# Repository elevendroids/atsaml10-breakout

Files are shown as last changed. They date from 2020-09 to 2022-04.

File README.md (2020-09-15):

# ATSAML1x Breakout Board (Rev. A)

Small breakout board designed for the [ATSAML10 and ATSAML11](https://ww1.microchip.com/downloads/en/DeviceDoc/SAM-L10L11-Family-DataSheet-DS60001513F.pdf) ARM Cortex-M23 MCUs from Microchip

## Features

- minimal subset of components, no power regulation etc.
- optional external main and real-time crystals - if not used, their GPIO pins can be connected to the user header by soldering relevant 0R resistors (see schematic)
- two buffered user LEDs, connected to the header - no reserved GPIOs
- reset button
- standard 0.05" pitch SWD programming header, SWD signals also present on the pin headers

Designed in KiCad 5.1.6

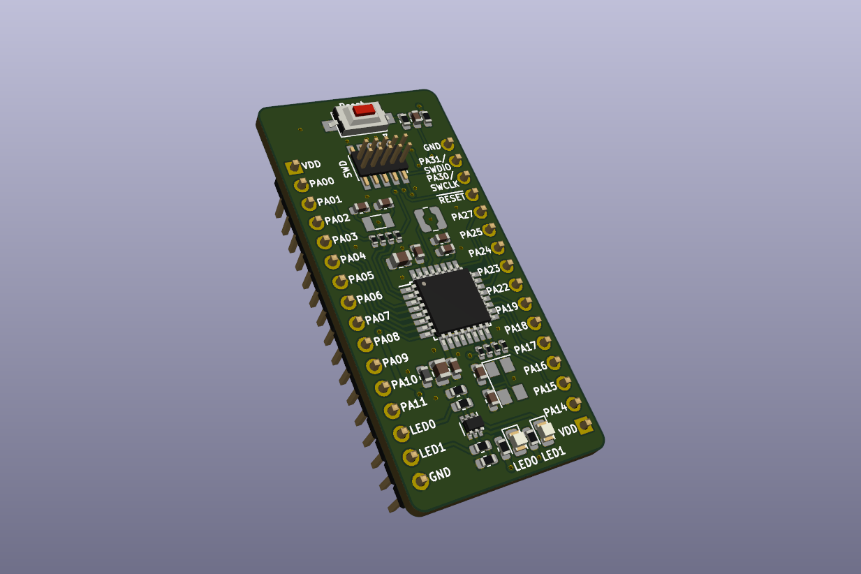
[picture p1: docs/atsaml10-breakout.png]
PCB Render


Schematic: [PDF](docs/atsaml10-breakout.pdf)

License: [CC BY-SA 4.0](https://creativecommons.org/licenses/by-sa/4.0/)

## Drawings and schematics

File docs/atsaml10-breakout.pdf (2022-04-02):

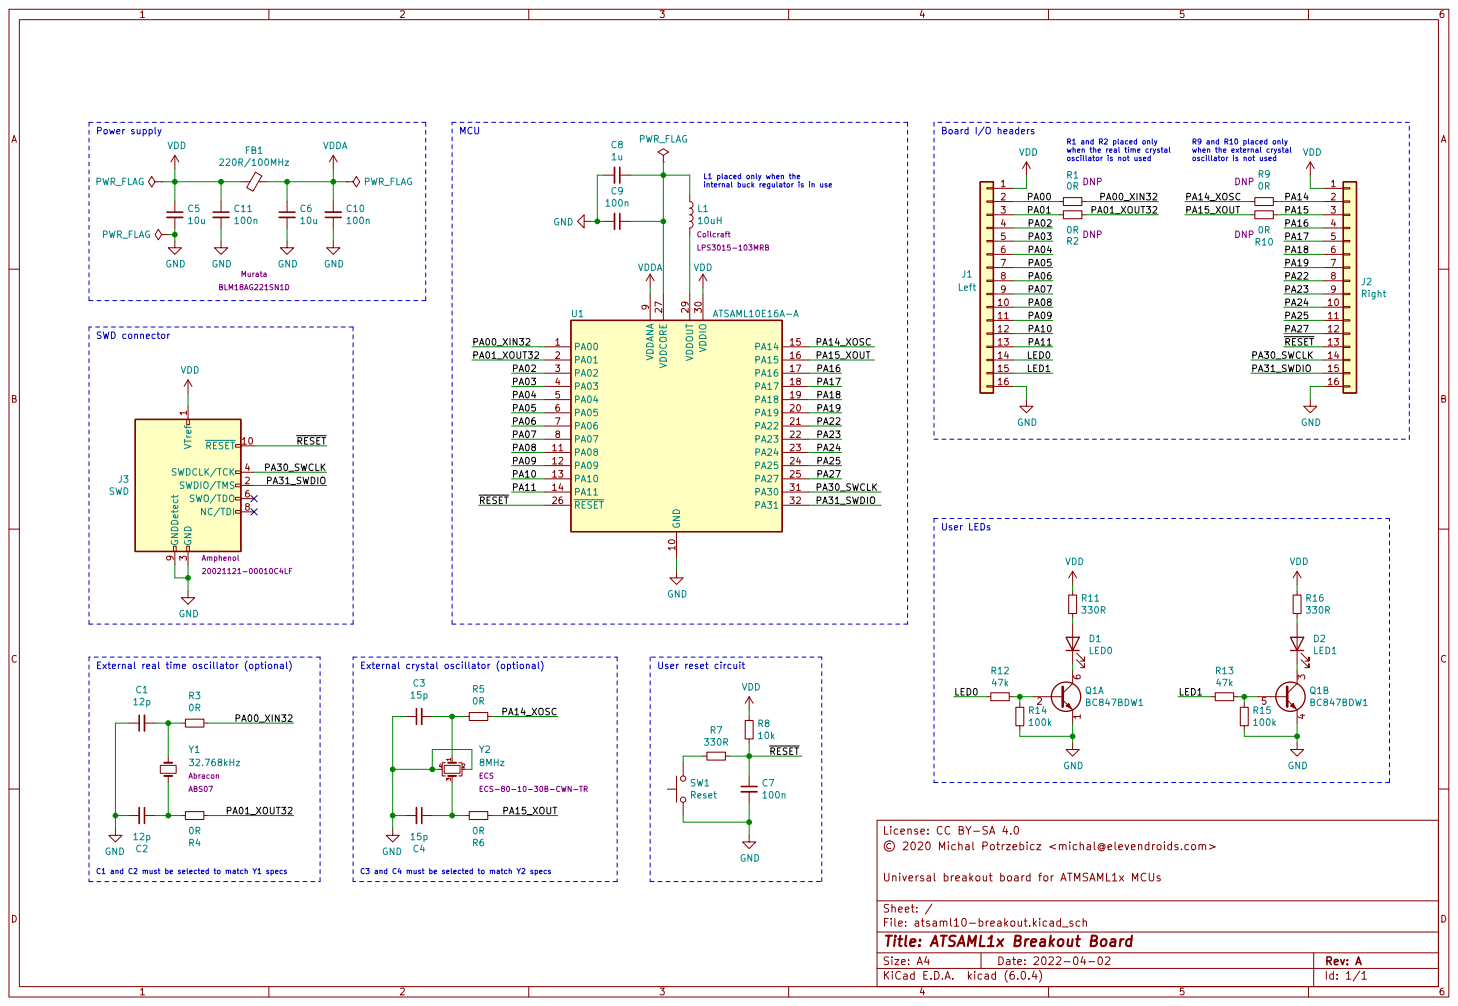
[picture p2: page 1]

R9 and R10 placed only when the external crystal oscillator is not used User reset circuit

PWR_FLAG
internal buck regulator is in use External crystal oscillator (optional) C1 and C2 must be selected to match Y1 specs
Amphenol 20021121-00010C4LF VDD

3 SWDCLK/TCK 4 SWO/TDO 6 NC/TDI 8 GNDDetect 9

License: CC BY-SA 4.0
File: atsaml10-breakout.kicad_sch Sheet: / Universal breakout board for ATMSAML1x MCUs þÿ© 2020 Michal Potrzebicz <michal@elevendroids.com>

Id: 1/1 Title: ATSAML1x Breakout Board

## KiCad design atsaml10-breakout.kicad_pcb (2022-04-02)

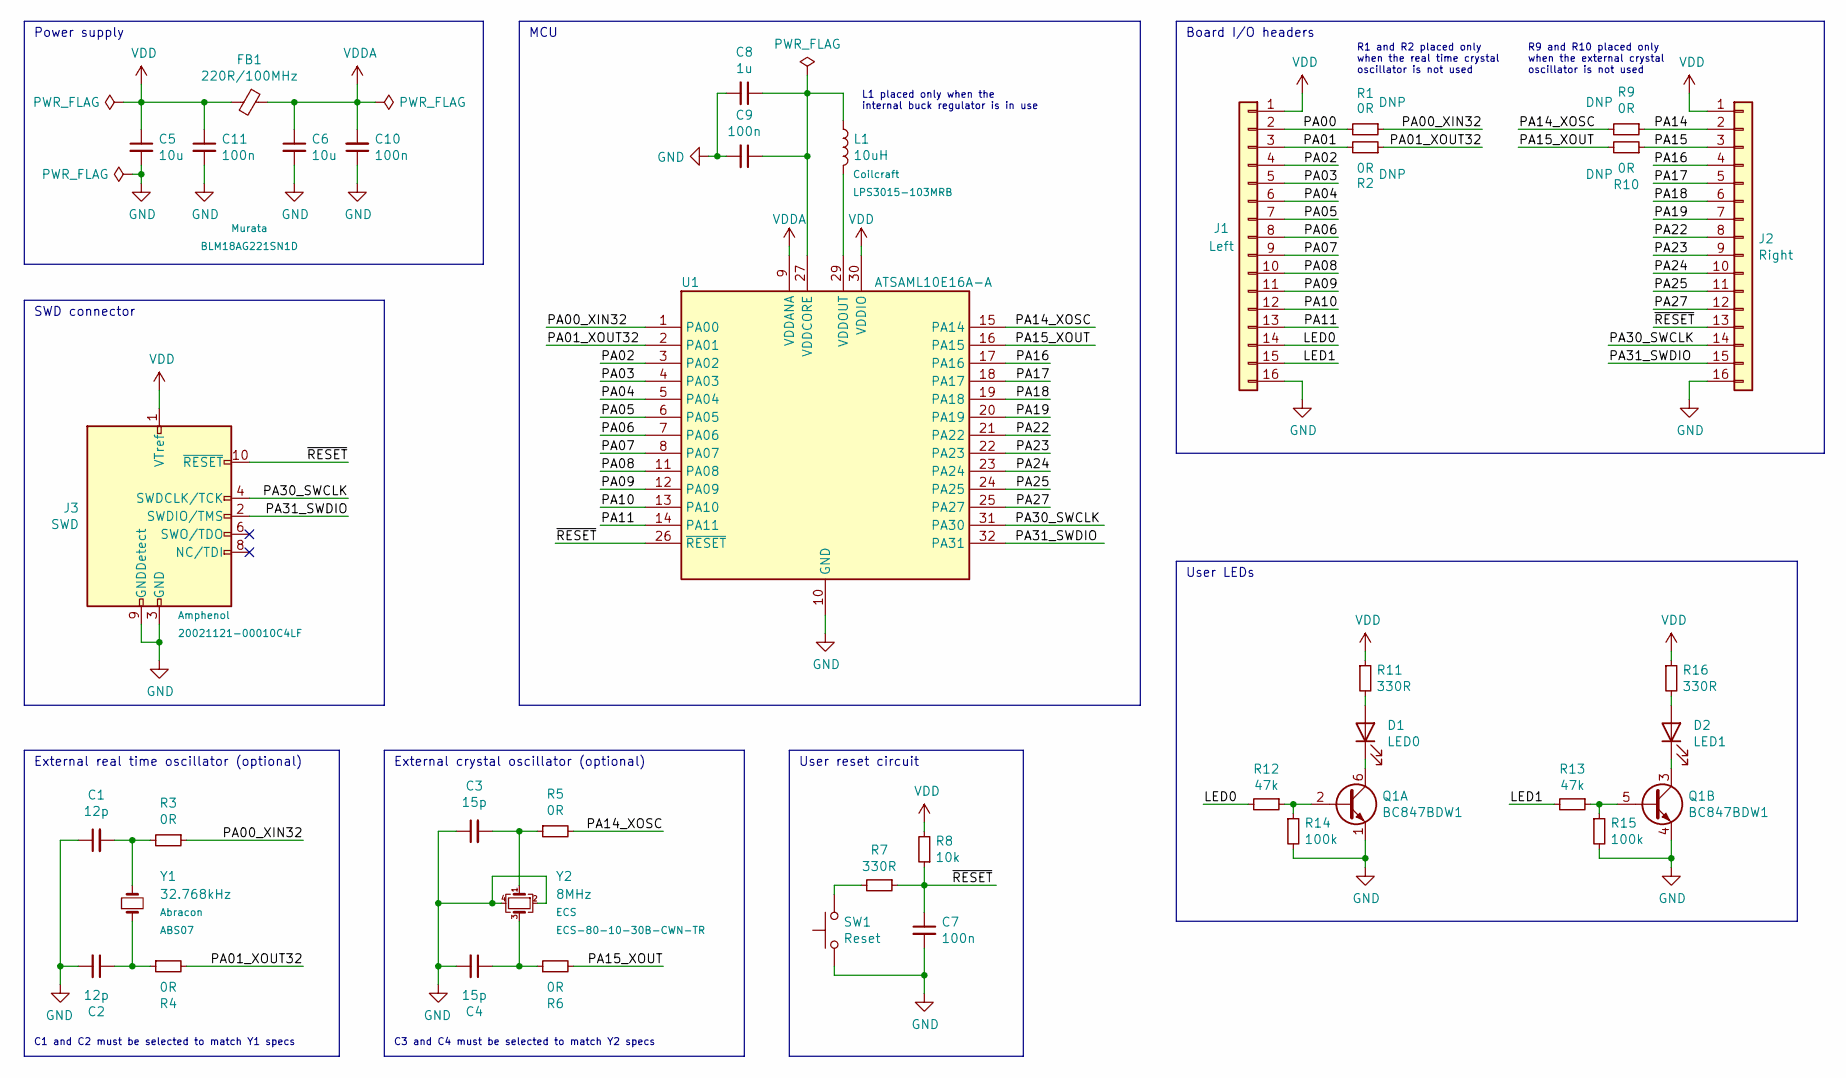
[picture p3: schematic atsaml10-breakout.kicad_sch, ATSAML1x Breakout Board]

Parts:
C1, C2: 12p; C_0603_1608Metric
C3, C4: 15p; C_0603_1608Metric
C5, C6: 10u; C_0805_2012Metric
C7, C9, C10, C11: 100n; C_0603_1608Metric
C8: 1u; C_0603_1608Metric
D1: LED0; LED_0805_2012Metric
D2: LED1; LED_0805_2012Metric
FB1: 220R/100MHz; L_0603_1608Metric; MPN BLM18AG221SN1D
J1: Left; PinHeader_1x16_P2.54mm_Vertical
J2: Right; PinHeader_1x16_P2.54mm_Vertical
J3: SWD; PinHeader_2x05_P1.27mm_Vertical_SMD; MPN 20021121-00010C4LF
L1: 10uH; L_Coilcraft_LPS3015; MPN LPS3015-103MRB
Q1: BC847BDW1; SOT-363_SC-70-6
R1, R2, R3, R4, R5, R6, R9, R10: 0R; R_0402_1005Metric
R7, R11, R16: 330R; R_0603_1608Metric
R8: 10k; R_0603_1608Metric
R12, R13: 47k; R_0603_1608Metric
R14, R15: 100k; R_0603_1608Metric
SW1: Reset; SW_SPST_CK_RS282G05A3
U1: ATSAML10E16A-A; TQFP-32_7x7mm_P0.8mm
Y1: 32.768kHz; Crystal_SMD_3215-2Pin_3.2x1.5mm; MPN ABS07
Y2: 8MHz; Crystal_SMD_5032-4Pin_5.0x3.2mm; MPN ECS-80-10-30B-CWN-TR

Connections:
/LED0: J1.14, R12.2
/LED1: J1.15, R13.2
/PA00: J1.2, R1.2
/PA00_XIN32: R1.1, R3.1, U1.1 (PA00)
/PA01: J1.3, R2.2
/PA01_XOUT32: R2.1, R4.2, U1.2 (PA01)
/PA02: J1.4, U1.3 (PA02)
/PA03: J1.5, U1.4 (PA03)
/PA04: J1.6, U1.5 (PA04)
/PA05: J1.7, U1.6 (PA05)
/PA06: J1.8, U1.7 (PA06)
/PA07: J1.9, U1.8 (PA07)
/PA08: J1.10, U1.11 (PA08)
/PA09: J1.11, U1.12 (PA09)
/PA10: J1.12, U1.13 (PA10)
/PA11: J1.13, U1.14 (PA11)
/PA14: J2.2, R9.1
/PA14_XOSC: R5.2, R9.2, U1.15 (PA14)
/PA15: J2.3, R10.1
/PA15_XOUT: R6.2, R10.2, U1.16 (PA15)
/PA16: J2.4, U1.17 (PA16)
/PA17: J2.5, U1.18 (PA17)
/PA18: J2.6, U1.19 (PA18)
/PA19: J2.7, U1.20 (PA19)
/PA22: J2.8, U1.21 (PA22)
/PA23: J2.9, U1.22 (PA23)
/PA24: J2.10, U1.23 (PA24)
/PA25: J2.11, U1.24 (PA25)
/PA27: J2.12, U1.25 (PA27)
/PA30_SWCLK: J2.14, J3.4 (SWDCLK/TCK), U1.31 (PA30)
/PA31_SWDIO: J2.15, J3.2 (SWDIO/TMS), U1.32 (PA31)
/~RESET: C7.1, J2.13, J3.10 (~RESET), R7.1, R8.1, U1.26 (~RESET)
GND: C1.1, C2.2, C3.1, C4.2, C5.2, C6.2, C7.2, C8.2, C9.2, C10.1, C11.2, J1.16, J2.16, J3.3 (GND), J3.5 (GND), J3.9 (GNDDetect), Q1.1 (E1), Q1.4 (E2), R14.2, R15.2, SW1.1, U1.10 (GND), U1.28 (GND), Y2.2, Y2.4
unnamed: C1.2, R3.2, Y1.2
unnamed: C2.1, R4.1, Y1.1
unnamed: C3.2, R5.1, Y2.1
unnamed: C4.1, R6.1, Y2.3
unnamed: C8.1, C9.1, L1.1, U1.27 (VDDCORE)
unnamed: D1.1 (K), Q1.6 (C1)
unnamed: D1.2 (A), R11.2
unnamed: D2.1 (K), Q1.3 (C2)
unnamed: D2.2 (A), R16.2
unnamed: L1.2, U1.29 (VDDOUT)
unnamed: Q1.2 (B1), R12.1, R14.1
unnamed: Q1.5 (B2), R13.1, R15.1
unnamed: R7.2, SW1.2
VDD: C5.1, C11.1, FB1.2, J1.1, J2.1, J3.1 (VTref), R8.2, R11.1, R16.1, U1.30 (VDDIO)
VDDA: C6.1, C10.2, FB1.1, U1.9 (VDDANA)

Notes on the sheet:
L1 placed only when the internal buck regulator is in use
MCU
Power supply
User LEDs
C3 and C4 must be selected to match Y2 specs
SWD connector
User reset circuit
Board I/O headers
R1 and R2 placed only when the real time crystal oscillator is not used
C1 and C2 must be selected to match Y1 specs
R9 and R10 placed only when the external crystal oscillator is not used
External real time oscillator (optional)
External crystal oscillator (optional)

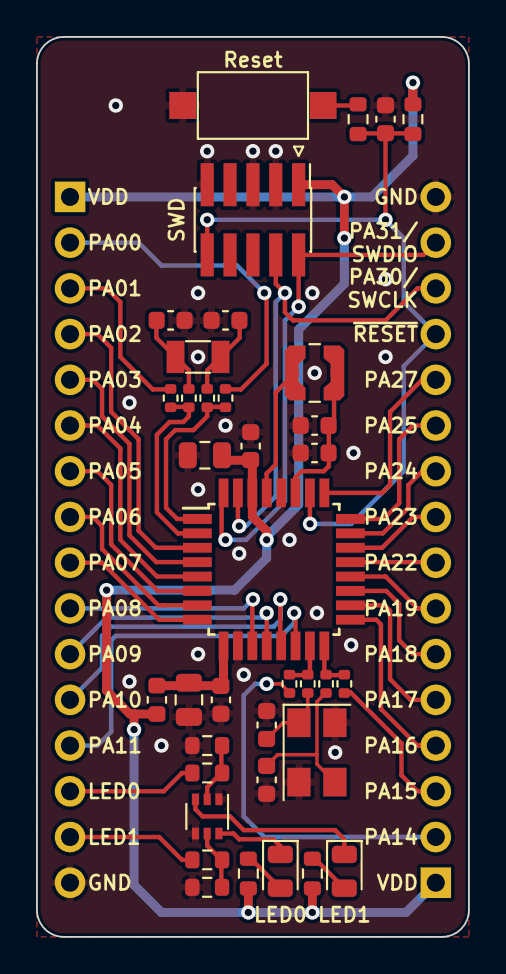
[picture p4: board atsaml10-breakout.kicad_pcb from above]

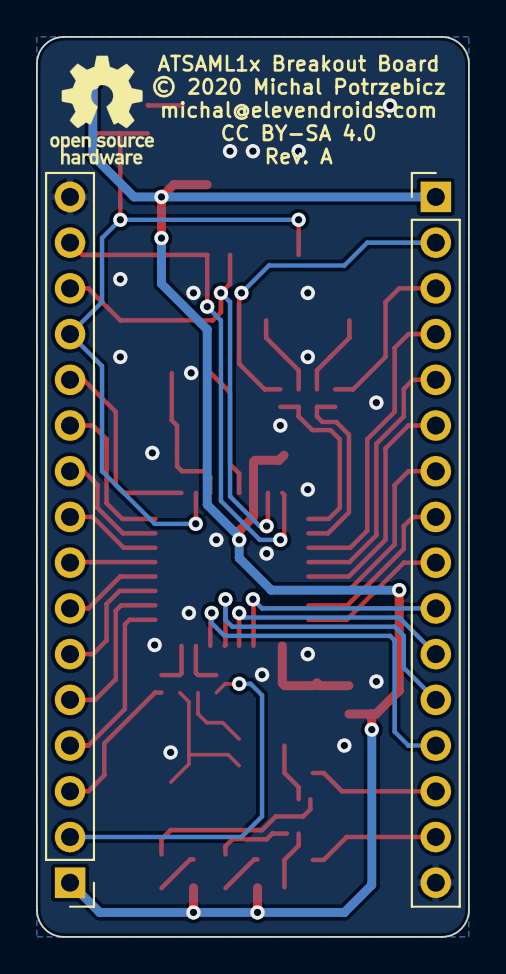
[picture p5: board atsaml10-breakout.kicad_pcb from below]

Board: 2 copper layers, 24.0 x 50.0 mm, 39 parts (2 on the bottom side), 48 nets.

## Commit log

2020-07-28 Initial commit, schematics almost complete
    [atsaml10-breakout.kicad_pcb, atsaml10-breakout.sch]
2020-07-28 Layout almost finished, added 2 LEDs, footprints tweaking
    Added two LEDs with simple transistor buffers connected to last two
    unused pins. They can be used for debugging, as indicators etc.
    Replaced C5 and C6 with 0805 parts as 10uF capacitors in 0603 are
    expensive.
    L1 footprint needs to be replaced as there are no matching 10uH
    inductors in 0603 case.
    Proposed replacement part: Coilcraft LPS3015-103MRB
    [atsaml10-breakout.kicad_pcb, atsaml10-breakout.sch]
2020-07-31 Replaced L1's footprint with Coilcraft LPS3015
    [atsaml10-breakout.kicad_pcb, atsaml10-breakout.sch]
2020-08-01 More layout tweaks
    [atsaml10-breakout.kicad_pcb]
2020-08-01 Tweaked copper pour zones settings
    [atsaml10-breakout.kicad_pcb]
2020-08-02 Schematic cleanup, more PCB tweaks
    [atsaml10-breakout.kicad_pcb, atsaml10-breakout.sch]
2020-08-14 PCB size tweaks, align headers to 0.1" grid
    [atsaml10-breakout.kicad_pcb]
2020-09-14 Getting revision A ready
    - Replaced Q1 and Q2 with BC847BDW1 and moved the chip to the front
    layer
    - Replaced 0R resistors' packages with 0402
    - Filled MFR and MPN fields for some parts
    - Added DNP fields for the option jumpers
    [atsaml10-breakout.kicad_pcb, atsaml10-breakout.sch]
2020-09-14 Interactive BOM
2020-09-15 Replaced Y2 footprint with a generic one
    [atsaml10-breakout.kicad_pcb, atsaml10-breakout.sch]
2020-09-15 Replaced Y1 footprint with a generic one
    [atsaml10-breakout.kicad_pcb, atsaml10-breakout.sch]
2020-09-15 Added README and a PCB render
2020-09-15 Cropped the PCB render a bit
2022-04-02 Project upgrade to KiCad 6
    [atsaml10-breakout.kicad_pcb, atsaml10-breakout.kicad_sch, atsaml10-breakout.sch]
